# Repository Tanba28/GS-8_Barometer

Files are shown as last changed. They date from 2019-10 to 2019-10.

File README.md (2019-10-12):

# GS-8_Barometer
GS-8 Barometer Board

Master project -> [project-arrows/GS-8](https://github.com/project-arrows/GS-8)

## Overview
 * GS-8気圧ロガー
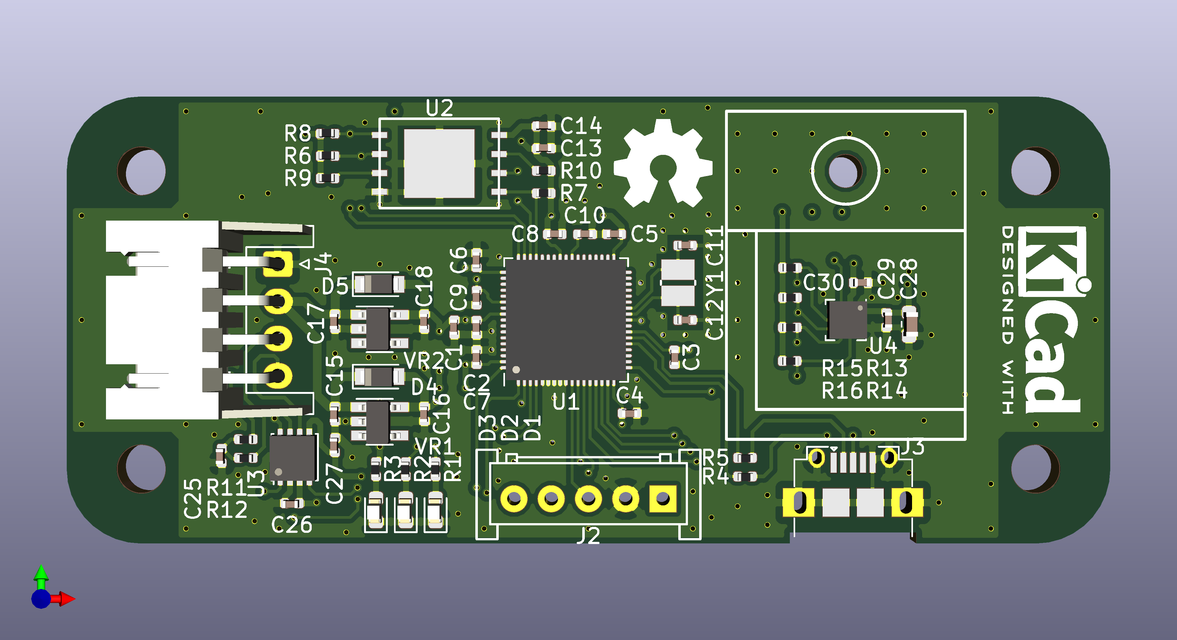
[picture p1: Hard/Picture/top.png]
top

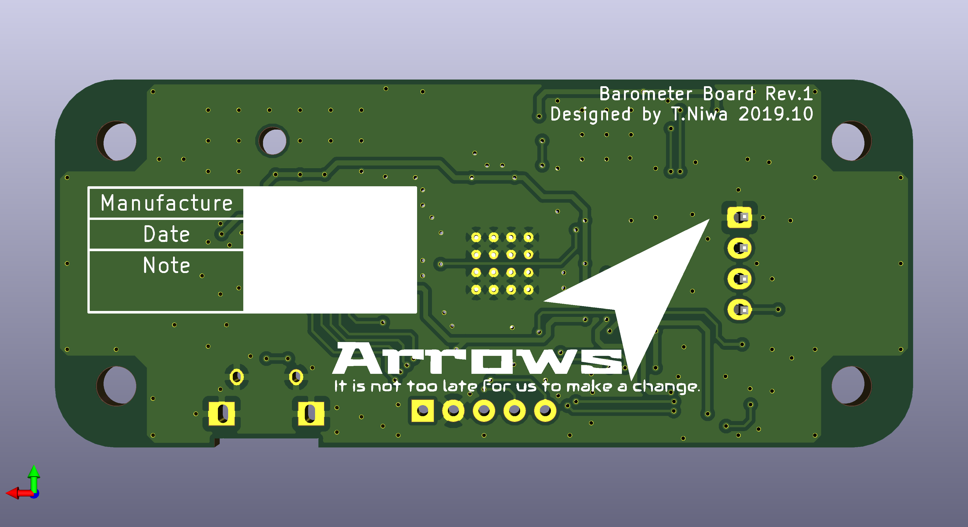
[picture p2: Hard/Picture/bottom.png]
bottom


## Role
 * 気圧をロギングする。
 * 頂点検知を行う。
 * 頂点検知結果を[開放基板](https://github.com/Tanba28/GS-8_PD_Board)に伝達する。

## Link
 * [Tanba28/GS-8_PM_Board](https://github.com/Tanba28/GS-8_PM_Board)
 * [Tanba28/GS-8_PD_Board](https://github.com/Tanba28/GS-8_PD_Board)
 * [Tanba28/GS-8_Motion_Logger](https://github.com/Tanba28/GS-8_Motion_Logger)
 * [Tanba28/GS-8_Relay_Board](https://github.com/Tanba28/GS-8_Relay_Board)
 * [ringo156/GS-8_ACCLRM_Board](https://github.com/ringo156/GS-8_ACCLRM_Board)
 * [takamasavvv/RCT-X_Logger](https://github.com/takamasavvv/RCT-X-Logger)
 * [takamasavvv/RCT-X-Telemetry](https://github.com/takamasavvv/RCT-X-Telemetry)
 
## LICENSE
MIT License

Copyright (c) 2019 Tanba28

Permission is hereby granted, free of charge, to any person obtaining a copy
of this software and associated documentation files (the "Software"), to deal
in the Software without restriction, including without limitation the rights
to use, copy, modify, merge, publish, distribute, sublicense, and/or sell
copies of the Software, and to permit persons to whom the Software is
furnished to do so, subject to the following conditions:

The above copyright notice and this permission notice shall be included in all
copies or substantial portions of the Software.

THE SOFTWARE IS PROVIDED "AS IS", WITHOUT WARRANTY OF ANY KIND, EXPRESS OR
IMPLIED, INCLUDING BUT NOT LIMITED TO THE WARRANTIES OF MERCHANTABILITY,
FITNESS FOR A PARTICULAR PURPOSE AND NONINFRINGEMENT. IN NO EVENT SHALL THE
AUTHORS OR COPYRIGHT HOLDERS BE LIABLE FOR ANY CLAIM, DAMAGES OR OTHER
LIABILITY, WHETHER IN AN ACTION OF CONTRACT, TORT OR OTHERWISE, ARISING FROM,
OUT OF OR IN CONNECTION WITH THE SOFTWARE OR THE USE OR OTHER DEALINGS IN THE
SOFTWARE.

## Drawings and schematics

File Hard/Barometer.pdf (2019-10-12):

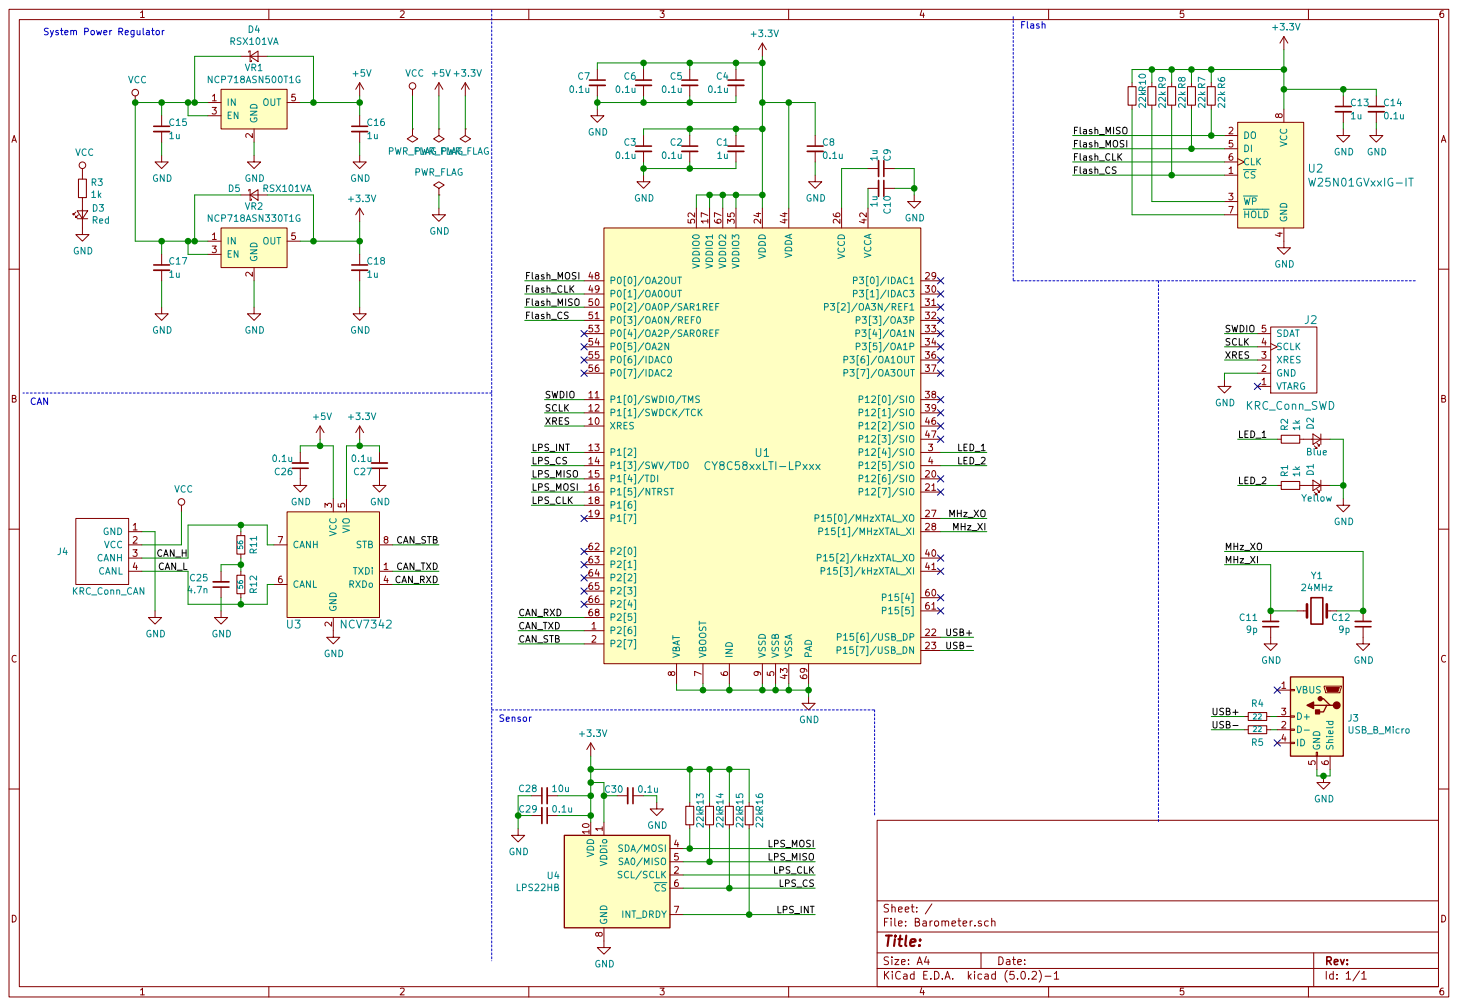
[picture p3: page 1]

8 U2W25N01GVxxIG-IT GND R6 22k +3.3V USB+ USB- USB+ USB- MHz_XO MHz_XI MHz_XO MHz_XI LED_1
0.1u R1 1k D2 Blue D1 Yellow GND

4 DI 5 CLK 6 HOLD 7 VCC

Id: 1/1 Title: File: Barometer.sch Sheet: / GND

1 VDD 10 SCL/SCLK 2 SDA/MOSI 4 SA0/MISO 5 CS 6

LPS_CLK
LPS_CS

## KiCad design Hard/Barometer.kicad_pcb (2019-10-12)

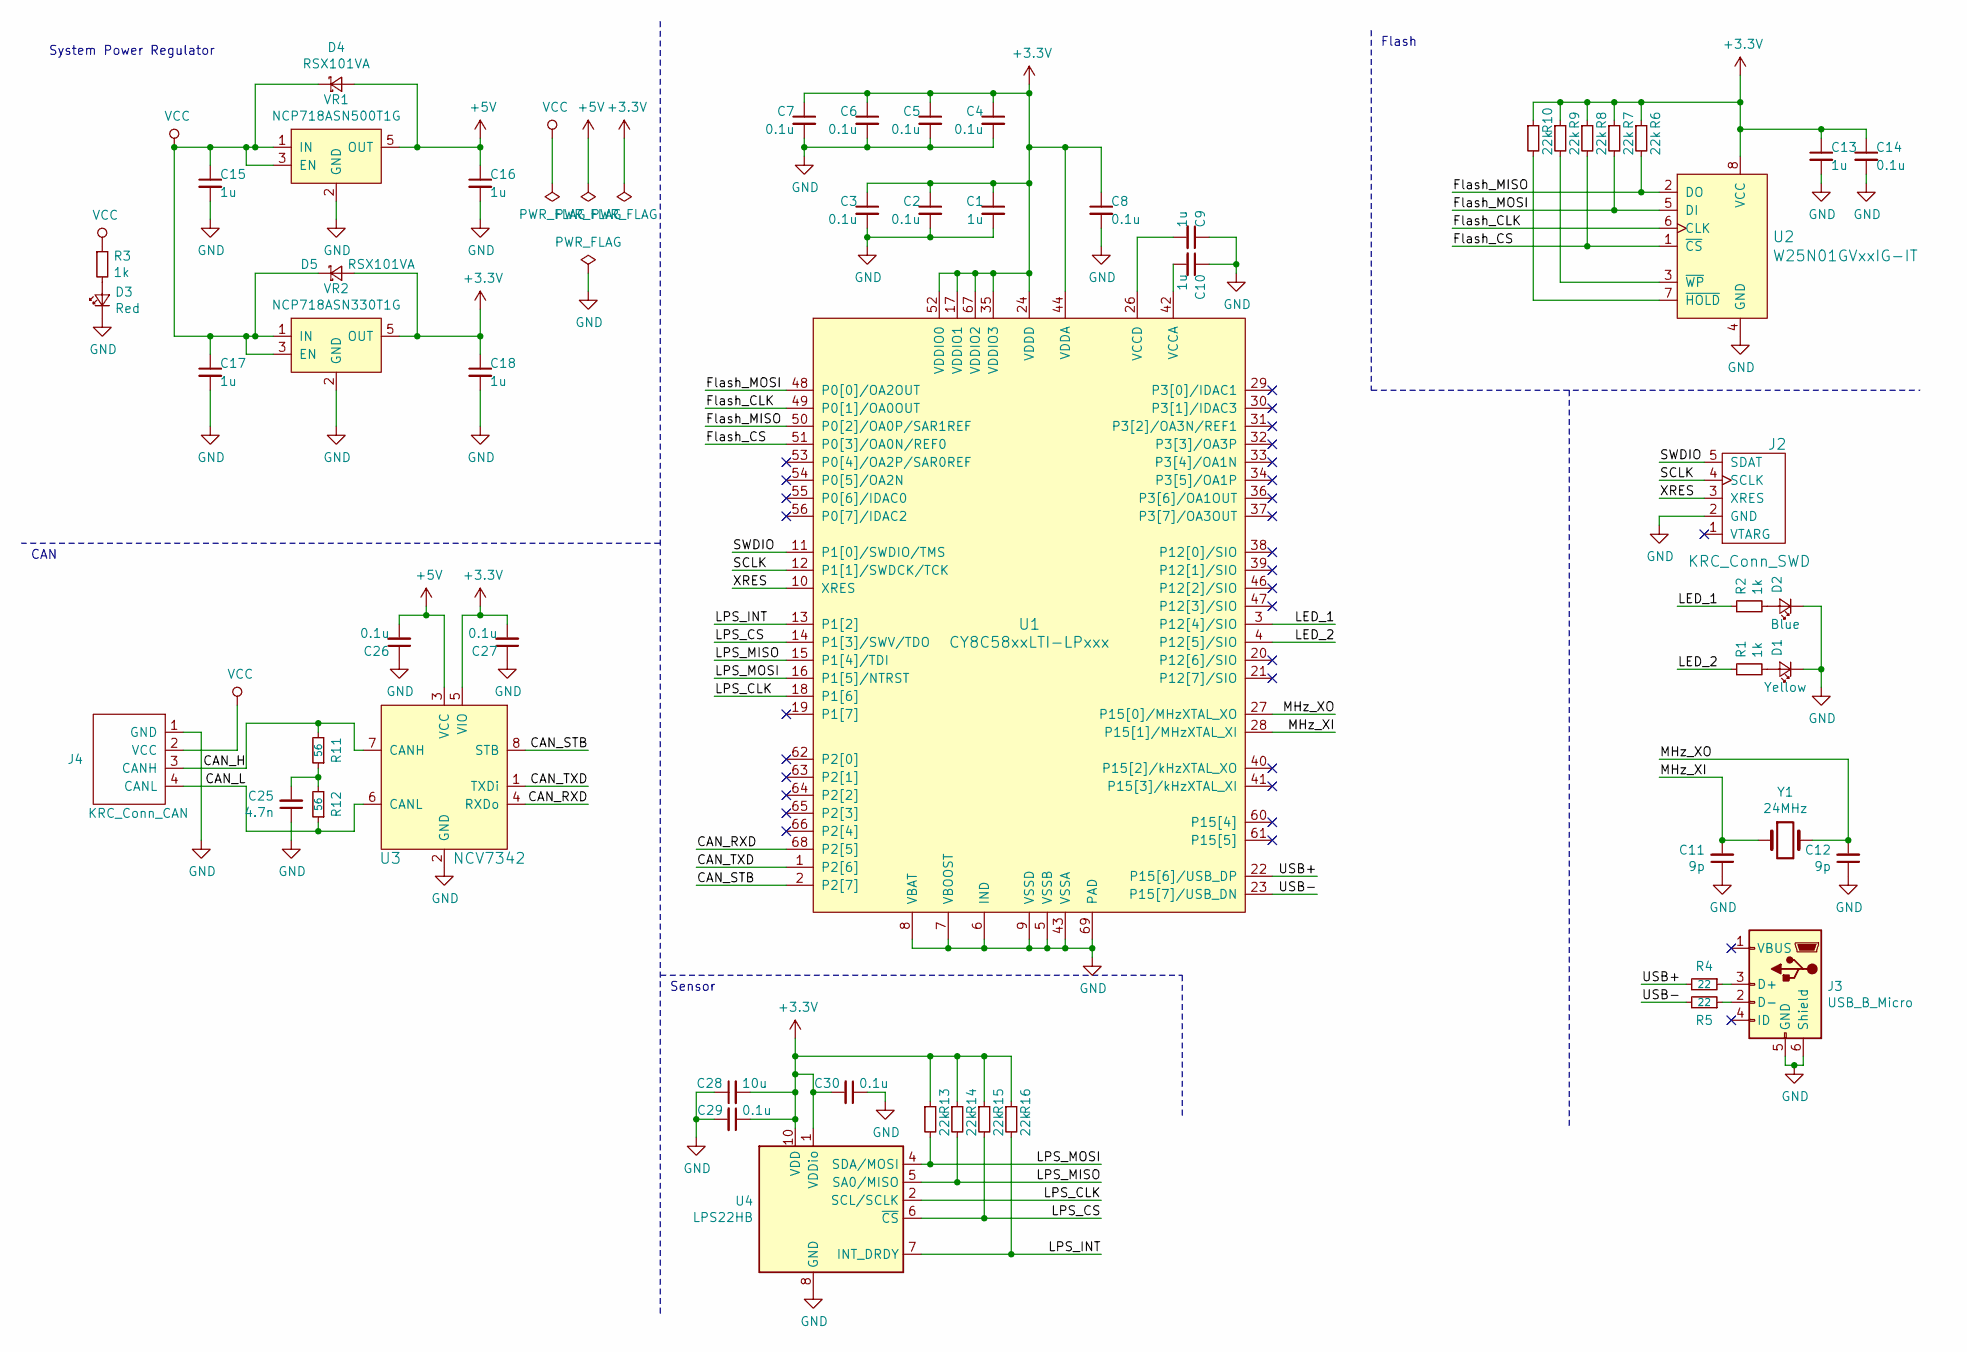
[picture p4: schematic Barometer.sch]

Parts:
C1, C9, C10, C13, C15, C16, C17, C18: 1u; C_0402_1005Metric; MPN GRM155R61E105KA12D
C2, C3, C4, C5, C6, C7, C8, C14, C26, C27, C29, C30: 0.1u; C_0402_1005Metric; MPN GRM155R62A104KE14D
C11, C12: 9p; C_0402_1005Metric; MPN GRM1555C1H9R0DA01D
C25: 4.7n; C_0402_1005Metric; MPN GRM155R71H472KA01D
C28: 10u; C_0603_1608Metric; MPN GRM188R6YA106MA73D
D1: Yellow; LED_0603_1608Metric
D2: Blue; LED_0603_1608Metric
D3: Red; LED_0603_1608Metric
D4, D5: RSX101VA; D_TUMD2; MPN RSX101VAM-30TR
J2: KRC_Conn_SWD; JST_JQ_05JQ-BT_1x05_P2.5mm_Vertical; MPN 05JQ-BT
J3: USB_B_Micro; Hirose_ZX_ZX62D-B-5P8; MPN ZX62D-B-5P8(30)
J4: KRC_Conn_CAN; JST_XH_S4B-XH-A_1x04_P2.50mm_Horizontal; MPN S4B-XH-A
R1, R2, R3: 1k; R_0402_1005Metric; MPN ERJ-2GEJ102X
R4, R5: 22; R_0402_1005Metric; MPN ERJ-2GEJ220X
R6, R7, R8, R9, R10, R13, R14, R15, R16: 22k; R_0402_1005Metric; MPN ERJ-2RKF2202X
R11, R12: 56; R_0402_1005Metric; MPN ERJ-2GEJ560X
U1: CY8C58xxLTI-LPxxx; Cypress_QFN-68_EP_8x8_Pitch0.4mm; MPN CY8C5868LTI-LP039
U2: W25N01GVxxIG-IT; WSON-8_8x6mm_P1.27mm; MPN W25N01GVZEIG TR
U3: NCV7342; DFN-8-1EP_3x3mm_P0.65mm_EP1.55x2.4mm; MPN NCV7342MW3R2G
U4: LPS22HB; ST_HLGA-10_2.5x2.5mm_P0.6mm_LayoutBorder3x2y; MPN LPS22HB
VR1: NCP718ASN500T1G; TSOT-23-5; MPN NCP718ASN500T1G
VR2: NCP718ASN330T1G; TSOT-23-5; MPN NCP718ASN330T1G
Y1: 24MHz; Crystal_Murata_XRCHA; MPN XRCHA24M000F0A01R0

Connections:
+3V3: C1.1, C2.1, C3.1, C4.1, C5.1, C6.1, C7.1, C8.1, C13.1, C14.1, C18.1, C27.2, C28.2, C29.1, C30.2, D5.2 (A), R6.1, R7.1, R8.1, R9.1, R10.1, R13.1, R14.1, R15.1, R16.1, U1.17 (VDDIO1), U1.24 (VDDD), U1.35 (VDDIO3), U1.44 (VDDA), U1.52 (VDDIO0), U1.59 (VDDD), U1.67 (VDDIO2), U2.8 (VCC), U3.5 (VIO), U4.1 (VDDio), U4.10 (VDD), VR2.5 (OUT)
+5V: C16.1, C26.2, D4.2 (A), U3.3 (VCC), VR1.5 (OUT)
/CAN_H: J4.3 (CANH), R11.2, U3.7 (CANH)
/CAN_L: J4.4 (CANL), R12.1, U3.6 (CANL)
/CAN_RXD: U1.68 (P2[5]), U3.4 (RXDo)
/CAN_STB: U1.2 (P2[7]), U3.8 (STB)
/CAN_TXD: U1.1 (P2[6]), U3.1 (TXDi)
/Flash_CLK: U1.49 (P0[1]/OA0OUT), U2.6 (CLK)
/Flash_CS: R8.2, U1.51 (P0[3]/OA0N/REF0), U2.1 (~CS)
/Flash_MISO: R6.2, U1.50 (P0[2]/OA0P/SAR1REF), U2.2 (DO)
/Flash_MOSI: R7.2, U1.48 (P0[0]/OA2OUT), U2.5 (DI)
/LED_1: R2.1, U1.3 (P12[4]/SIO)
/LED_2: R1.1, U1.4 (P12[5]/SIO)
/LPS_CLK: U1.18 (P1[6]), U4.2 (SCL/SCLK)
/LPS_CS: R15.2, U1.14 (P1[3]/SWV/TDO), U4.6 (~CS)
/LPS_INT: R16.2, U1.13 (P1[2]), U4.7 (INT_DRDY)
/LPS_MISO: R14.2, U1.15 (P1[4]/TDI), U4.5 (SA0/MISO)
/LPS_MOSI: R13.2, U1.16 (P1[5]/NTRST), U4.4 (SDA/MOSI)
/MHz_XI: C11.2, U1.28 (P15[1]/MHzXTAL_XI), Y1.1
/MHz_XO: C12.2, U1.27 (P15[0]/MHzXTAL_XO), Y1.2
/SCLK: J2.4 (SCLK), U1.12 (P1[1]/SWDCK/TCK)
/SWDIO: J2.5 (SDAT), U1.11 (P1[0]/SWDIO/TMS)
/USB+: R4.2, U1.22 (P15[6]/USB_DP)
/USB-: R5.2, U1.23 (P15[7]/USB_DN)
/XRES: J2.3 (XRES), U1.10 (XRES)
GND: C1.2, C2.2, C3.2, C4.2, C5.2, C6.2, C7.2, C8.2, C9.1, C10.1, C11.1, C12.1, C13.2, C14.2, C15.2, C16.2, C17.2, C18.2, C25.1, C26.1, C27.1, C28.1, C29.2, C30.1, D1.1 (K), D2.1 (K), D3.1 (K), J2.2 (GND), J3.5 (GND), J3.6 (Shield), J4.1 (GND), U1.5 (VSSB), U1.6 (IND), U1.7 (VBOOST), U1.8 (VBAT), U1.9 (VSSD), U1.25 (VSSD), U1.43 (VSSA), U1.45 (VSSD), U1.58 (VSSD), U1.69 (PAD), U2.4 (GND), U2.9, U3.2 (GND), U3.9, U4.3 (GND), U4.8 (GND), U4.9 (GND), VR1.2 (GND), VR2.2 (GND)
unnamed: C9.2, U1.26 (VCCD), U1.57 (VCCD)
unnamed: C10.2, U1.42 (VCCA)
unnamed: C25.2, R11.1, R12.2
unnamed: D1.2 (A), R1.2
unnamed: D2.2 (A), R2.2
unnamed: D3.2 (A), R3.2
unnamed: J3.2 (D-), R5.1
unnamed: J3.3 (D+), R4.1
unnamed: R9.2, U2.3 (~WP)
unnamed: R10.2, U2.7 (~HOLD)
VCC: C15.1, C17.1, D4.1 (K), D5.1 (K), J4.2 (VCC), R3.1, VR1.1 (IN), VR1.3 (EN), VR2.1 (IN), VR2.3 (EN)

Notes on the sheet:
System Power Regulator
Flash
Sensor
CAN

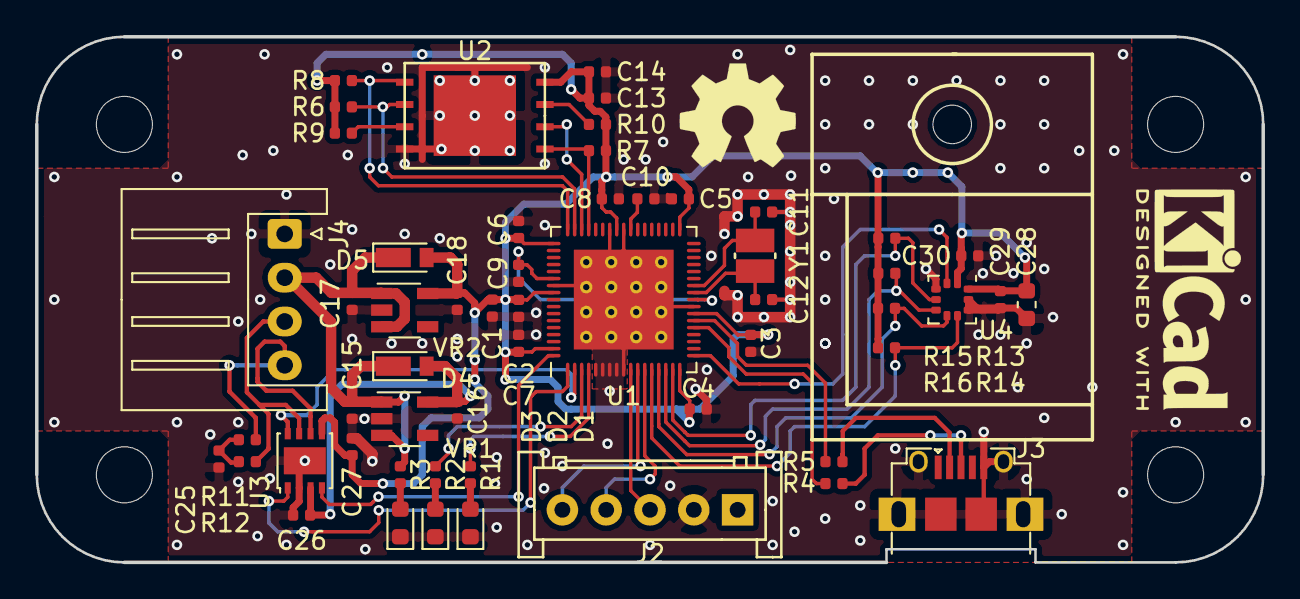
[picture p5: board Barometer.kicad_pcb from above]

Board: 2 copper layers, 70.0 x 30.0 mm, 55 parts (0 on the bottom side), 37 nets.

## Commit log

2019-10-12 [add] ハード完成。ガーバ出力
    [Barometer-B.Cu.gbl, Barometer-B.Mask.gbs, Barometer-B.Paste.gbp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]
2019-10-12 [update] 回路図のフィールドを編集
    [Barometer.sch]
2019-10-12 [update] READMEを整備
    [Barometer.kicad_pcb]
2019-10-12 [add] READMEを整備
